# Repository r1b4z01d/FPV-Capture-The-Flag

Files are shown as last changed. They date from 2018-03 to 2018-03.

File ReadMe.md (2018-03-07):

#Intro
  This game is intended to extend the curently available interactive FPV drone games. This could possibly be extended to be used as an led gate that changes color as each pilot passes through it. 

##Game Directions
  Up to four pilots can play at a time. As many flags as posible spread out. The objective is to fly as close to each flag as possible until the flag changes to the players color. My initial (untested) idea was to have no set course and pilots would openly fly what ever path to what ever flag next. If a head on collision is to happen each pilot must bail to their right. 

##Hardware required
* Arduino Pro Mini 5V 16Mhz 
* RX5805 Module
* Polu 5V Regulator
* WS2811B LED Strip

##Game Options
* Pilot VTX Channels
* Pilot Colors
* Number of LEDs
* RSSI Trigger
* LED Update speed

##To do: 
* Split/cleanup code
* Finalize PDB design
* Finish the readme
* How to video
* Add Bluetooth, WIFI and/or UWB
* Create Mobile App
* Update LICENSE 

##Thanks
With out @voroshkov's work on [Chorus-RF-Laptimer](https://github.com/voroshkov/Chorus-RF-Laptimer) this never could have been done. I will split out his code and will include the MIT notice.

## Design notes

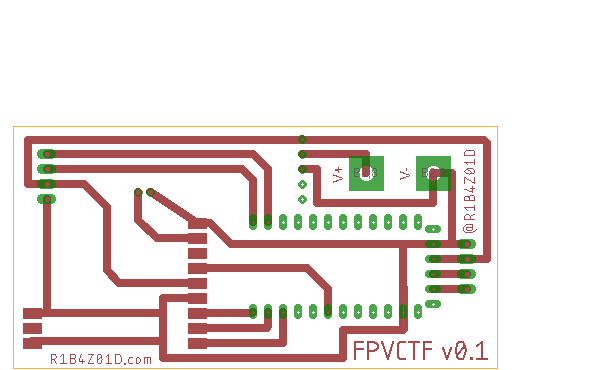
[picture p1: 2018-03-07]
pcb/FPVCTV.png

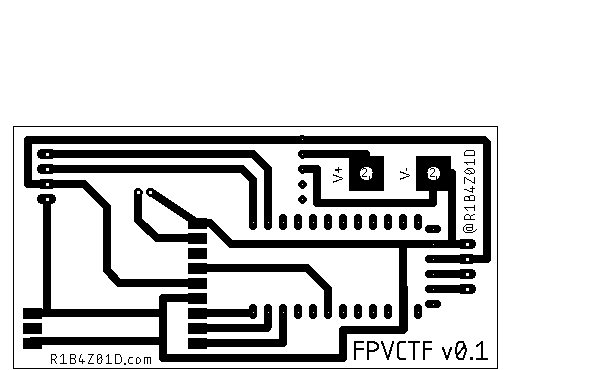
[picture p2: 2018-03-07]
pcb/FPVCTV_Mono.png

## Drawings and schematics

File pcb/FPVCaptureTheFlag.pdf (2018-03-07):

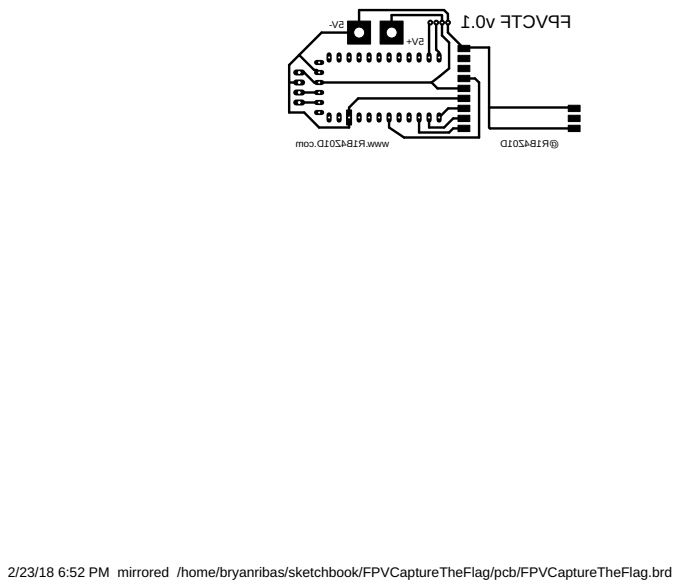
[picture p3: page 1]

2/23/18 6:52 PM mirrored /home/bryanribas/sketchbook/FPVCaptureTheFlag/pcb/FPVCaptureTheFlag.brd

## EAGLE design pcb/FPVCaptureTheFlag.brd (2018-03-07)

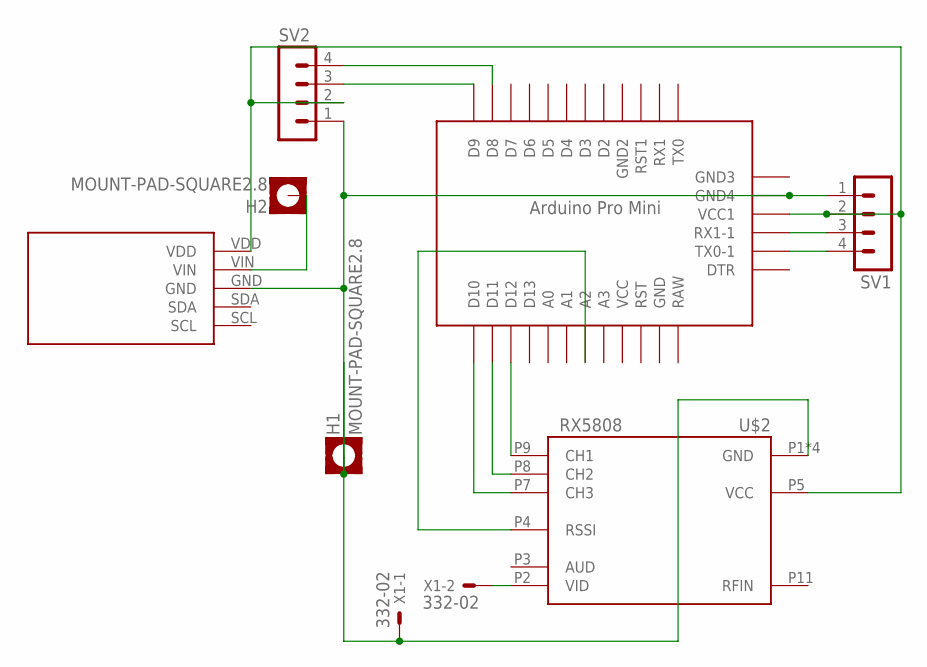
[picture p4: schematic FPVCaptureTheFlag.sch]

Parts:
H1, H2: MOUNT-PAD-SQUARE2.8; 2,8-PAD-SQUARE
SV1, SV2: MA04-1
U$1: ABK-PRO-MINI
U$2: RX5808
U$3: POLOLU_MINIMU9_V2THROUGHHOLE; POLOLU_MINIMU9_V2
X1: 332-02

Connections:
unnamed: U$1.D12, U$2.P9 (CH1)
unnamed: U$1.D11, U$2.P8 (CH2)
unnamed: U$1.D10, U$2.P7 (CH3)
unnamed: U$1.A2, U$2.P4 (RSSI)
unnamed: SV2.4, U$1.D8
unnamed: SV2.3, U$1.D9
unnamed: H2.B2,8, U$3.VIN
unnamed: SV1.3, U$1.RX1-1
unnamed: SV1.4, U$1.TX0-1
unnamed: H1.B2,8, SV1.1, SV2.1, U$1.GND3 (GND4), U$2.P1 (GND), U$2.P6 (GND), U$2.P10 (GND), U$2.P12 (GND), U$3.GND, X1.1
unnamed: U$2.P2 (VID), X1.2
unnamed: SV1.2, SV2.2, U$1.VCC1, U$2.P5 (VCC), U$3.VDD

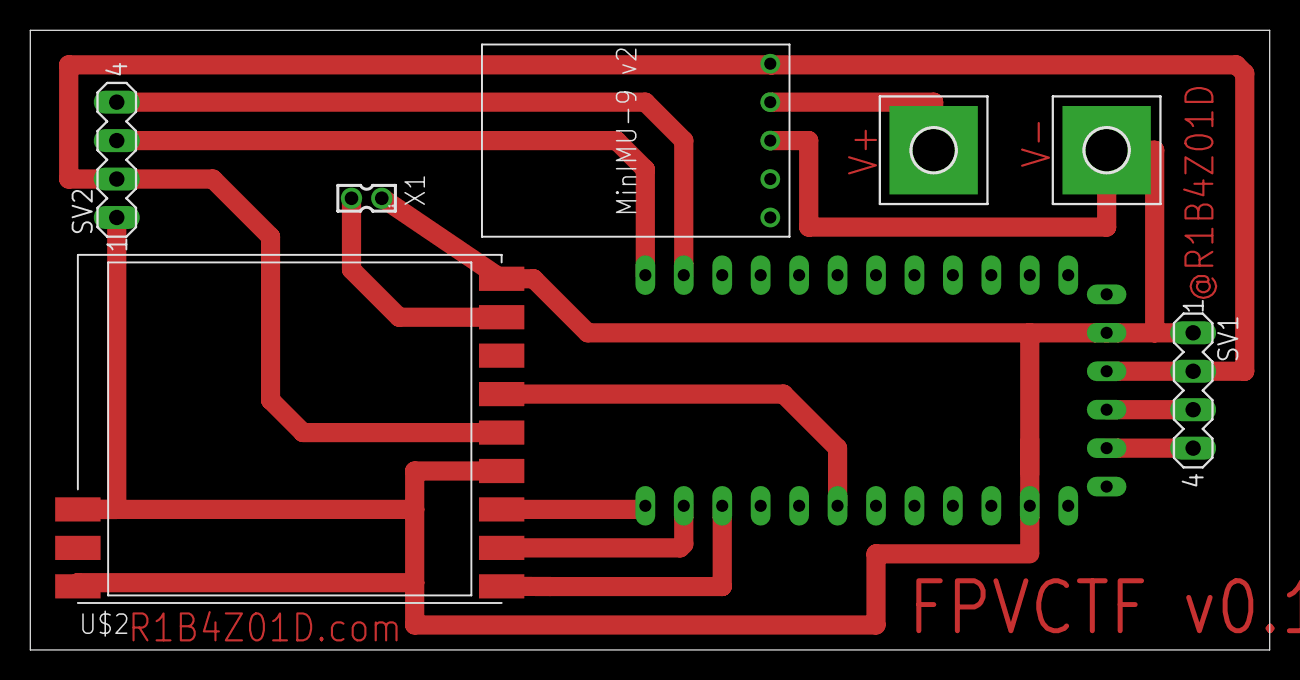
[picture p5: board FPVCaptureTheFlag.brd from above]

Board: 2 copper layers, 81.9 x 40.9 mm, 8 parts (0 on the bottom side), 12 nets.

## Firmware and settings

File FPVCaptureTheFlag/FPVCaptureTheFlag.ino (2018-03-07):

/*
-----------------------------
  02.20.2018
  BryanRibas@gmail.com @R1B4Z01D
  http://www.R1B4Z01D.com
  With out @voroshkov's work on Chorus-RF-Laptimer this never could have been done. I will split out his code to include the MIT notice. 
  https://github.com/voroshkov/Chorus-RF-Laptimer
  -----------------------------
*/
#include <FastLED.h>

//----Pin config
#define DATA_PIN 9
#define RSSI_ADC A2
#define SPI_DATA_PIN 10
#define SPI_SS_PIN 11
#define SPI_CLOCK_PIN 12

// Config, vars and stats
#define NUM_LEDS 75
#define RSSI_DELAY 50
#define LED_UPDATE_DELAY 10
#define RSSI_TRIGGER 230

int channels[]={0,2,4,6};
int bands[]={4,4,4,4};
int rssis[]={0,0,0,0};
int stats[]={0,0,0,0};
CRGB::HTMLColorCode pilotColor[] = {CRGB::Red,CRGB::Purple,CRGB::Blue,CRGB::Green};
int captured = 0;
int brightness = 10;
uint8_t gHue = 0;
CRGB leds[NUM_LEDS];
CRGB::HTMLColorCode lastColor = CRGB::White;

void setLEDColors(void){
  ////set every led color
  for(int i=0; i<= (NUM_LEDS/2);i++){
    leds[i] = lastColor;    
    leds[NUM_LEDS-i] = lastColor;
    delay(LED_UPDATE_DELAY);
    FastLED.show();
  }//end change led colors
}
// --------------------------------------------------------
const uint16_t channelTable[] PROGMEM = {
    // Channel 1 - 8
    0x281D, 0x288F, 0x2902, 0x2914, 0x2987, 0x2999, 0x2A0C, 0x2A1E, // Raceband 0
    0x2A05, 0x299B, 0x2991, 0x2987, 0x291D, 0x2913, 0x2909, 0x289F, // Band A 1
    0x2903, 0x290C, 0x2916, 0x291F, 0x2989, 0x2992, 0x299C, 0x2A05, // Band B 2
    0x2895, 0x288B, 0x2881, 0x2817, 0x2A0F, 0x2A19, 0x2A83, 0x2A8D, // Band E 3
    0x2906, 0x2910, 0x291A, 0x2984, 0x298E, 0x2998, 0x2A02, 0x2A0C, // Band F 4
    0x2609, 0x261C, 0x268E, 0x2701, 0x2713, 0x2786, 0x2798, 0x280B  // Band D 5
};

void SERIAL_SENDBIT1() {
    digitalWrite(SPI_CLOCK_PIN, LOW);
    delayMicroseconds(1);

    digitalWrite(SPI_DATA_PIN, HIGH);
    delayMicroseconds(1);
    digitalWrite(SPI_CLOCK_PIN, HIGH);
    delayMicroseconds(1);

    digitalWrite(SPI_CLOCK_PIN, LOW);
    delayMicroseconds(1);
}

void SERIAL_SENDBIT0() {
    digitalWrite(SPI_CLOCK_PIN, LOW);
    delayMicroseconds(1);

    digitalWrite(SPI_DATA_PIN, LOW);
    delayMicroseconds(1);
    digitalWrite(SPI_CLOCK_PIN, HIGH);
    delayMicroseconds(1);

    digitalWrite(SPI_CLOCK_PIN, LOW);
    delayMicroseconds(1);
}

void SERIAL_ENABLE_LOW() {
    delayMicroseconds(1);
    digitalWrite(SPI_SS_PIN, LOW);
    delayMicroseconds(1);
}

void SERIAL_ENABLE_HIGH() {
    delayMicroseconds(1);
    digitalWrite(SPI_SS_PIN, HIGH);
    delayMicroseconds(1);
}

void setChannelModule(uint8_t channel, uint8_t band) {
    uint8_t i;
    uint16_t channelData;

    channelData = pgm_read_word_near(channelTable + channel + (8 * band));

    // bit bang out 25 bits of data
    // Order: A0-3, !R/W, D0-D19
    // A0=0, A1=0, A2=0, A3=1, RW=0, D0-19=0
    SERIAL_ENABLE_HIGH();
    delayMicroseconds(1);
    SERIAL_ENABLE_LOW();

    SERIAL_SENDBIT0();
    SERIAL_SENDBIT0();
    SERIAL_SENDBIT0();
    SERIAL_SENDBIT1();

    SERIAL_SENDBIT0();

    // remaining zeros
    for (i = 20; i > 0; i--) {
        SERIAL_SENDBIT0();
    }

    // Clock the data in
    SERIAL_ENABLE_HIGH();
    delayMicroseconds(1);
    SERIAL_ENABLE_LOW();

    // Second is the channel data from the lookup table
    // 20 bytes of register data are sent, but the MSB 4 bits are zeros
    // register address = 0x1, write, data0-15=channelData data15-19=0x0
    SERIAL_ENABLE_HIGH();
    SERIAL_ENABLE_LOW();

    // Register 0x1
    SERIAL_SENDBIT1();
    SERIAL_SENDBIT0();
    SERIAL_SENDBIT0();
    SERIAL_SENDBIT0();

    // Write to register
    SERIAL_SENDBIT1();

    // D0-D15
    //   note: loop runs backwards as more efficent on AVR
    for (i = 16; i > 0; i--) {
        // Is bit high or low?
        if (channelData & 0x1) {
            SERIAL_SENDBIT1();
        }
        else {
            SERIAL_SENDBIT0();
        }
        // Shift bits along to check the next one
        channelData >>= 1;
    }

    // Remaining D16-D19
    for (i = 4; i > 0; i--) {
        SERIAL_SENDBIT0();
    }

    // Finished clocking data in
    SERIAL_ENABLE_HIGH();
    delayMicroseconds(1);

    digitalWrite(SPI_SS_PIN, LOW);
    digitalWrite(SPI_CLOCK_PIN, LOW);
    digitalWrite(SPI_DATA_PIN, LOW);
}

void updateRSSI(void){
  for(int i=0;i<4;i++){
     setChannelModule(channels[i],bands[i]);    
     delay(RSSI_DELAY);
     rssis[i] = analogRead(RSSI_ADC);
  }
}

void printData(void){
  for(int i =0;i<4;i++){
    Serial.print(rssis[i]);
    Serial.print(" ");
    Serial.print(stats[i]);
    Serial.print(" ");
  }
    Serial.println("");
}

void setup(void) {
    FastLED.addLeds<WS2811, DATA_PIN, GRB>(leds, NUM_LEDS);
    Serial.begin(9600);
    pinMode(SPI_SS_PIN, OUTPUT);
    pinMode(SPI_CLOCK_PIN, OUTPUT);
    pinMode(SPI_DATA_PIN, OUTPUT);
    //setLEDColors();
    FastLED.setBrightness(brightness);
    fill_rainbow( leds, NUM_LEDS, 0, 7);
    FastLED.show(); 
    delay(1000);
}

void loop(void) {
  updateRSSI();
  int maxRSSI = max(max(rssis[0], rssis[1]),max(rssis[2],rssis[3]));
  if (maxRSSI >= RSSI_TRIGGER){
    for(int i=0;i<4;i++){
       if(maxRSSI==rssis[i]){
        if(lastColor!=pilotColor[i]){
            stats[i]++;
            lastColor=pilotColor[i];
            setLEDColors();
            captured = 1;
        }
       }
    }
  }//end if any RSSI > RSSI_TRIGGER

  printData();  
  if(!captured){ 
    fill_rainbow( leds, NUM_LEDS, gHue, 5);
    FastLED.show();
    gHue++; // slowly cycle the "base color" through the rainbow  
  }
  
}//end loop
